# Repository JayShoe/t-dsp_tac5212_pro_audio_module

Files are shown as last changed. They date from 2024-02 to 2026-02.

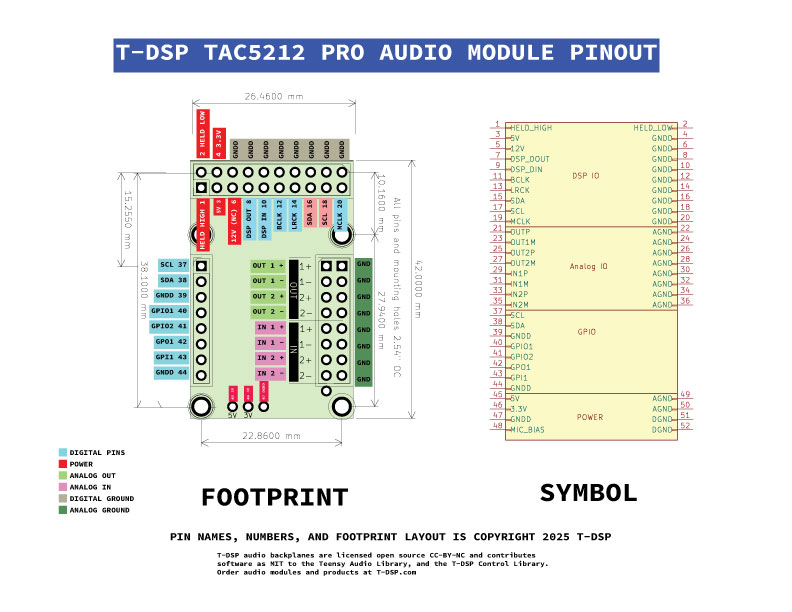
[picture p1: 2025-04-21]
documentation/T-DSP-TAC5212-PRO-AUDIO-MODULE-PINOUT.jpg

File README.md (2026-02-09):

# T-DSP TAC5212 Pro Audio Module

**Part of the [T-DSP](https://t-dsp.com) open modular audio platform.**

A compact (50mm x 34.5mm) stereo audio codec module built around the **Texas Instruments TAC5212** high-performance audio codec.

T-DSP TAC5212 Pro Audio Module

T-DSP TAC5212 Pro Audio Module - 3D Top
T-DSP TAC5212 Pro Audio Module - 3D Bottom

## About T-DSP

T-DSP is an open modular audio platform designed for musicians, engineers, and developers who want powerful digital signal processing in a flexible, hackable format. Built around the [Teensy](https://www.pjrc.com/teensy/) microcontroller and the [Teensy Audio Library](https://www.pjrc.com/teensy/td_libs_Audio.html), T-DSP combines studio-quality audio with a growing library of open-source modules for mixing, synthesis, effects, and more.

Whether you're building a custom digital mixer, crafting a unique instrument, or prototyping audio products, T-DSP gives you the tools to bring your ideas to life.

Join the community, contribute to the library, or grab a module and start patching. Learn more at [t-dsp.com](https://t-dsp.com).

## Overview

This codec module provides stereo ADC and DAC conversion and is one of the core building blocks of the T-DSP platform. It is designed as a **chip-on-board module** -- a complete, self-contained audio codec that solders directly onto a user-designed backplane PCB, just like any other component. A KiCad footprint is provided so you can drop the module into your own backplane design, add whatever jacks and connectors your application needs, and build a custom audio device without dealing with codec layout or analog design.

## Audio Capabilities

### Inputs (2 differential pairs)
- Line-level (consumer -10dBV or professional +4dBu)
- Instrument-level (guitar/bass) with external preamp/buffer (preamp and buffer modules are on the T-DSP project roadmap)
- Microphone (dynamic, with up to 12dB analog channel gain and additional digital gain)
- Programmable input impedance (5k/10k/40k ohm), DC-coupled. Optional 100k ohm bias resistors on board.
- 2 VRMS full-scale differential input

### Outputs (2 differential pairs)
- Headphone drive (16-300 ohm, 62.5mW @ 16 ohm, ~31mW @ 32 ohm)
- Consumer line out (-10dBV)
- Professional balanced output (+4dBu)
- 10 ohm output impedance, 2 VRMS differential output

## Digital Interface

- **I2S/PCM** audio data (DIN, DOUT, BCLK, LRCK, MCLK)
- **I2C** control bus for codec register configuration
- **GPIO** pins for additional control and sensing

The T-DSP platform is developed with [Teensy](https://www.pjrc.com/teensy/) and the [Teensy Audio Library](https://www.pjrc.com/teensy/td_libs_Audio.html), but the module uses standard I2S and I2C interfaces and can work with any compatible microcontroller or DSP platform.

## Modular Architecture

The module connects to your backplane via **2.54mm (0.1") header pins** (52 pins total), organized into functional groups. Headers can be male/female for a removable connection, or soldered permanently with straight pins:

- **DSP IO** (20 pins) -- digital audio (I2S), I2C control, MCLK, and power. Also available as a 20-pin ribbon header for off-board connection via standard ribbon cable.
- **Analog IO** (16 pins) -- stereo input and output pairs with analog ground references.
- **GPIO** (8 pins) -- additional I2C, general-purpose IO, and digital ground.
- **Power** (8 pins) -- 5V, 3.3V, MIC_BIAS, and ground lines.

T-DSP TAC5212 Pro Audio Module Pinout

### Backplane Integration

A KiCad footprint for the module is included in `/lib_fp/`, allowing you to import it directly into your own backplane PCB design. You handle the jacks, connectors, and mechanical layout on your backplane -- the module takes care of codec, filtering, and power regulation.

T-DSP TAC5212 Pro Audio Module Footprint

**Example backplanes built with the T-DSP module:**

Backplane example - prototype

Backplane example - 3D front
Backplane example - 3D back

### Multi-Module Chaining

Because the digital outputs are buffered on each module, multiple modules can run together on the same digital bus. You can daisy-chain modules in two ways:

- **On the backplane** -- route the digital bus as board traces between multiple module footprints.
- **Via ribbon cable** -- use a ribbon cable with multiple taps to connect up to 4 modules per chain.

System designers only need to focus on analog signal routing. The buffered digital bus works reliably over longer distances and across many modules.

## On-Board Circuitry

- LDO regulator for clean 3.3V analog power
- Buffered digital outputs for reliable backplane distribution
- TVS protection on audio outputs
- Ferrite bead RF filtering on audio inputs
- Solder jumpers for I2C address configuration
- Power indicator LED

The T-DSP platform has gone through several design iterations. The bench prototype below is from an earlier version of the project -- a different module architecture that helped shape the current design.

Earlier T-DSP prototype on the bench

## Project Files

| Directory | Contents |
|---|---|
| `/3d_models/` | 3D models for PCB components and enclosure |
| `/documentation/` | TAC5212 datasheets, [schematic PDF](documentation/t-dsp-tac5212-schematic.pdf), [footprint drawing](documentation/t-dsp-tac5212-footprint.pdf), and [3D model (STL)](documentation/t-dsp_tac5212_pro_audio_module.stl). View online: [schematic](https://kicanvas.org/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) and [PCB layout](https://kicanvas.org/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) via KiCanvas |
| `/lib_fp/` | Custom KiCad footprint libraries |
| `/lib_sch/` | Custom KiCad schematic symbol libraries |
| `/scripts/` | LCSC enrichment and BOM verification scripts |

## Building Manufacturing Files

Manufacturing files (gerbers, drill, BOMs, CPL, interactive BOM) are generated automatically by [KiBot](https://github.com/INTI-CMNB/KiBot) via GitHub Actions on every push to `main`. Download the ZIP from the **Actions** tab or from **Releases**.

The ZIP includes:
- Gerbers and drill files for any PCB fabricator
- JLCPCB BOM (`*_bom_JLCPCB.csv`) with LCSC part numbers
- Generic BOM (`*_bom_generic.csv`) with manufacturer part numbers
- Pick and place / CPL file
- Schematic PDF and PCB layout PDF
- Interactive BOM (also deployed live: [view iBOM](https://t-dsp.github.io/t-dsp_tac5212_pro_audio_module/ibom.html))

To build locally, install [Docker](https://www.docker.com/) and run:

```powershell
docker run --rm -v "${PWD}:/workspace" -w /workspace ghcr.io/inti-cmnb/kicad9_auto:latest kibot -c .kibot.yaml -b t-dsp_tac5212_pro_audio_module.kicad_pcb -e t-dsp_tac5212_pro_audio_module.kicad_sch -d manufacturing
```

Output files appear in `manufacturing/t-dsp_tac5212_pro_audio_module/`.

## Related Projects

Browse all T-DSP modules and backplanes on the [T-DSP GitHub organization](https://github.com/orgs/t-dsp/repositories).

## Status

This revision has not yet been built. The previous board was functional but had a few signal routing errors and needed a redesign of the analog output stage for low-impedance headphone drive. Those issues have been addressed in the current design.

If you build one, we'd love to hear how it goes -- please open an issue or reach out with your findings.

## Contact

For consulting, custom backplane design, or commercial licensing inquiries, reach out via [LinkedIn](https://linkedin.com/in/jayshoe).

## License

This project is licensed under the [Creative Commons Attribution-NonCommercial-ShareAlike 4.0 International (CC BY-NC-SA 4.0)](https://creativecommons.org/licenses/by-nc-sa/4.0/).

You are free to share and adapt this work for non-commercial purposes, as long as you give appropriate credit and distribute any derivatives under the same license.

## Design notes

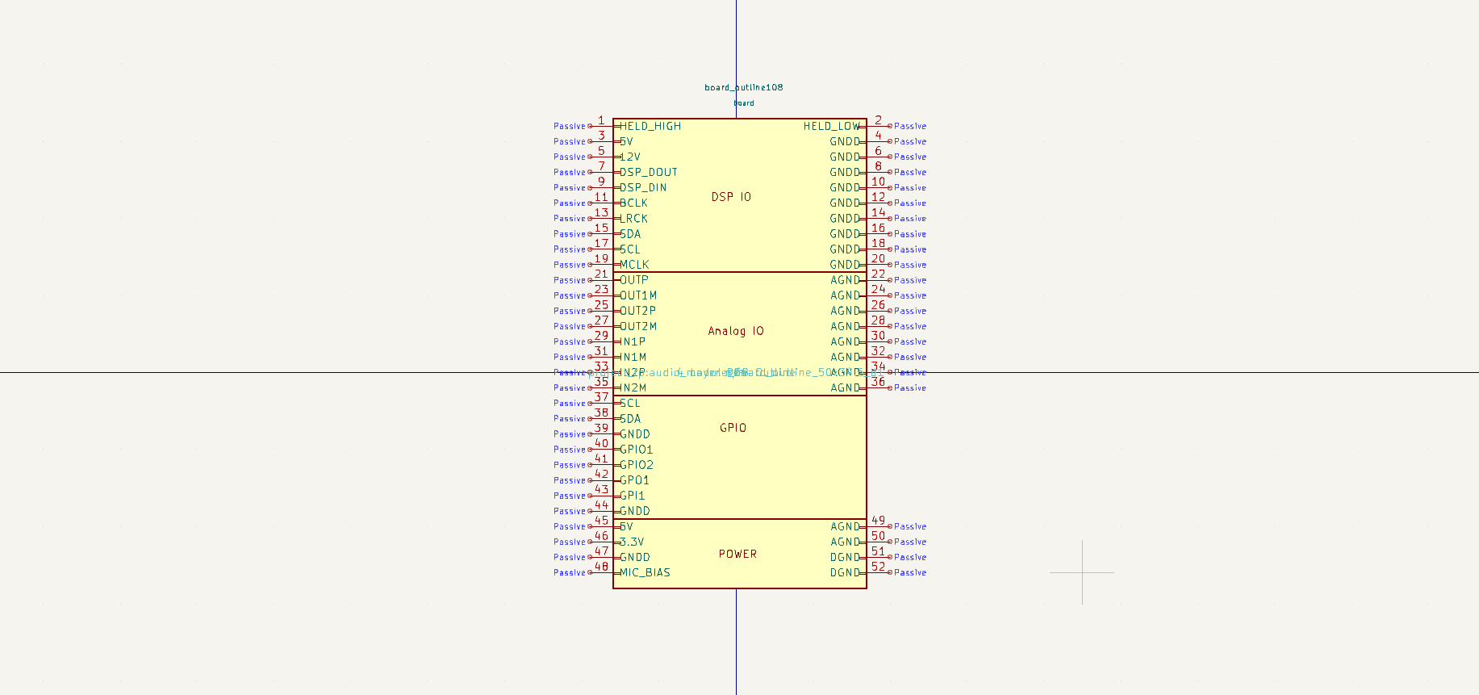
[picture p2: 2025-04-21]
documentation/T-DSP-TAC5212-PRO-AUDIO-MODULE-SYMBOL.png

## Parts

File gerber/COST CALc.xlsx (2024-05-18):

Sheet: TAC5212
Items | 1 quantity price | 100 price | 500 price | 1000 price | 2000 | 3000
components | 15.53 | 5.09 | 3.48 | 3.19 | 2.98 | 2.84
tacXXXX | 9.239 | 8.096 | 5.676 | 4.574 | 4.574 | 4.574
board | 2 | 0.33 | 0.08 | 0.08 | 0.08 | 0.08
assembly | 10 | 10 | 10 | 10 | 10 | 10
Total | 36.769 | 23.516 | 19.236 | 17.844 | 17.634 | 17.494
Price | 147.076 | 94.064 | 76.944 | 71.376 | 70.536 | 69.976
200 | 0.05 | 10

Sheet: TAC5112
Items | 1 quantity price | 100 price | 500 price | 1000 price | 2000 | 3000
components | 15.53 | 5.09 | 3.48 | 3.19 | 2.98 | 2.84
tacXXXX | 4.448 | 3.898 | 2.733 | 2.202 | 2.202 | 2.202
board | 2 | 0.33 | 0.08 | 0.08 | 0.08 | 0.08
assembly | 10 | 10 | 10 | 10 | 10 | 10
Total | 31.978 | 19.318 | 16.293 | 15.472 | 15.262 | 15.122
Price | 127.912 | 77.272 | 65.172 | 61.888 | 61.048 | 60.488

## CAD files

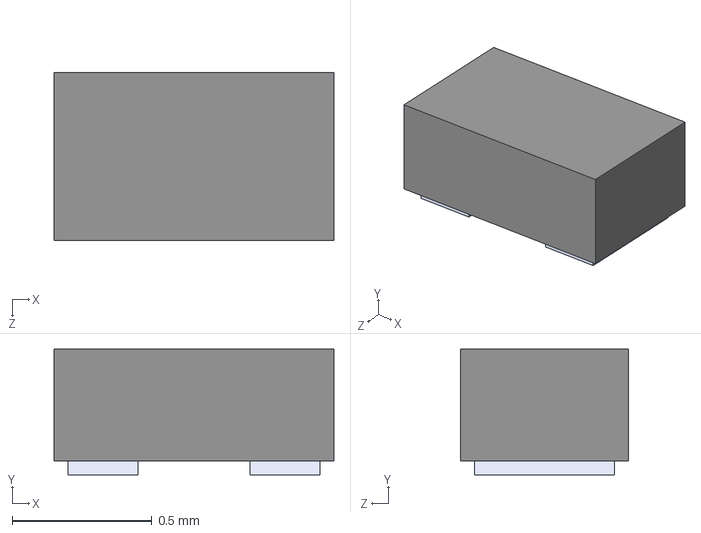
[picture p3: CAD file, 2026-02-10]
3d_models/TPD1E10B06DPYR.STEP
1.00 x 0.45 x 0.6 mm

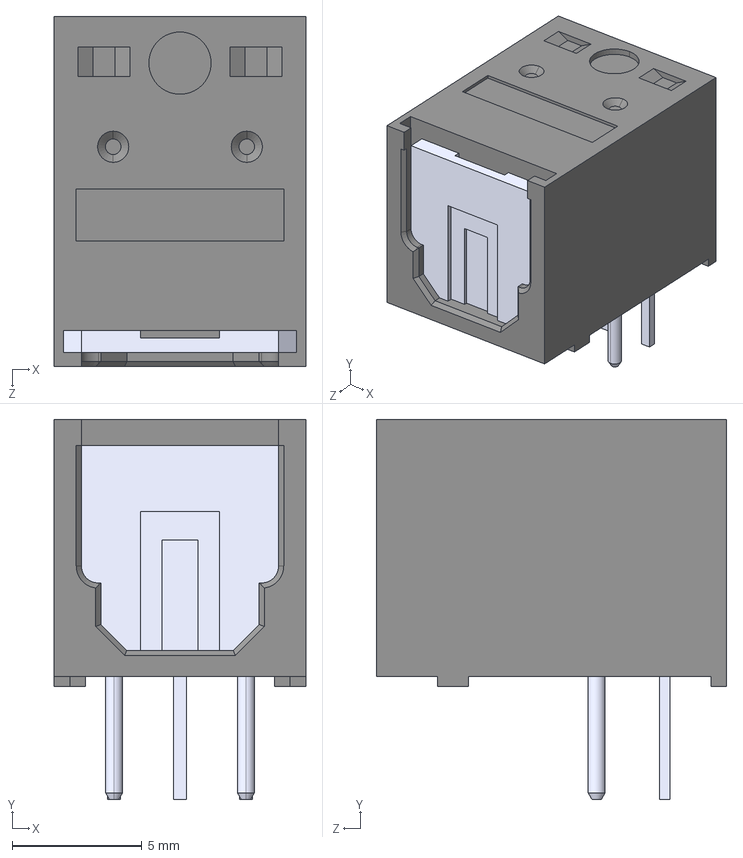
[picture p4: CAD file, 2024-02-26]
lib_sch/PLT133_T10W/PLT133_T10W.step
9.70 x 14.7 x 13.5 mm

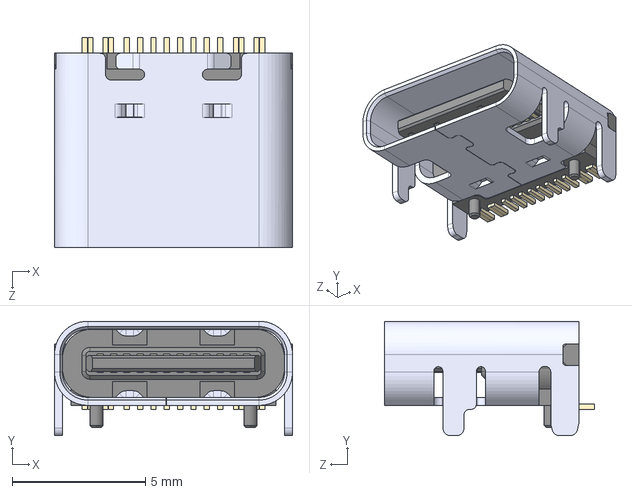
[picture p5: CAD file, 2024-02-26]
lib_sch/TYPE-C-31-M-12/TYPE-C-31-M-12.step
8.94 x 4.30 x 7.90 mm

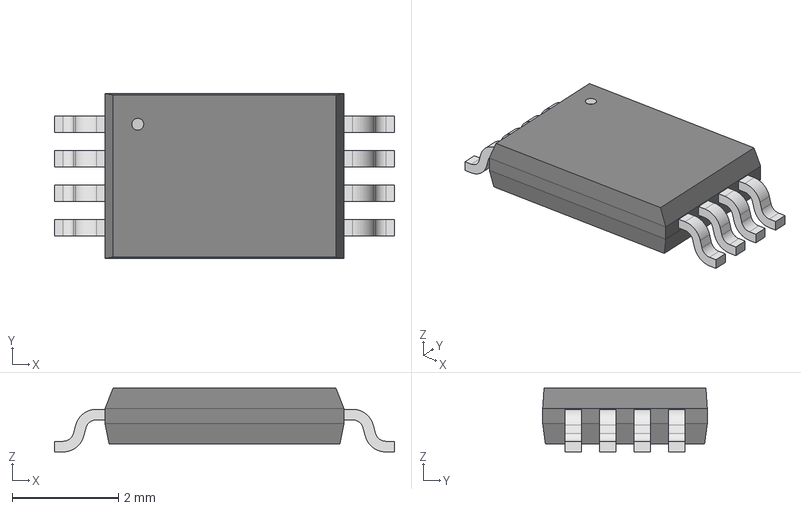
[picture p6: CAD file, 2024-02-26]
lib_sch/ul_23LC1024IST/2020-04-10_17-26-26/STEP/TSSOP8_MC.step
6.40 x 3.10 x 1.20 mm

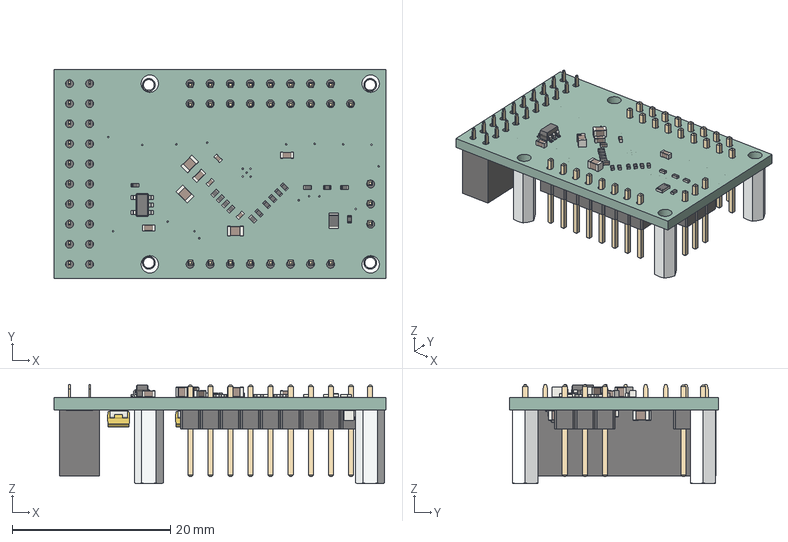
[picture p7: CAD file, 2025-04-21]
tlv320aic3105_audio_board50.step
42.0 x 26.5 x 12.5 mm
R_0402_1005Metric x 16
PinHeader_1x08_P254mm_Vertical x 2
PinHeader_1x09_P254mm_Vertical
PinSocket_2x10_P2.54mm_Vertical
PinHeader_1x03_P254mm_Vertical
C_0805_2012Metric x 9
C_0402_1005Metric x 3
SOT_23_5 x 2
C_0603_1608Metric x 13
R_0805_2012Metric
R_0603_1608Metric x 4
CP_EIA_3528_21_Kemet_B x 4
_autosave-tac5212_audio_board_single_ended_PCB

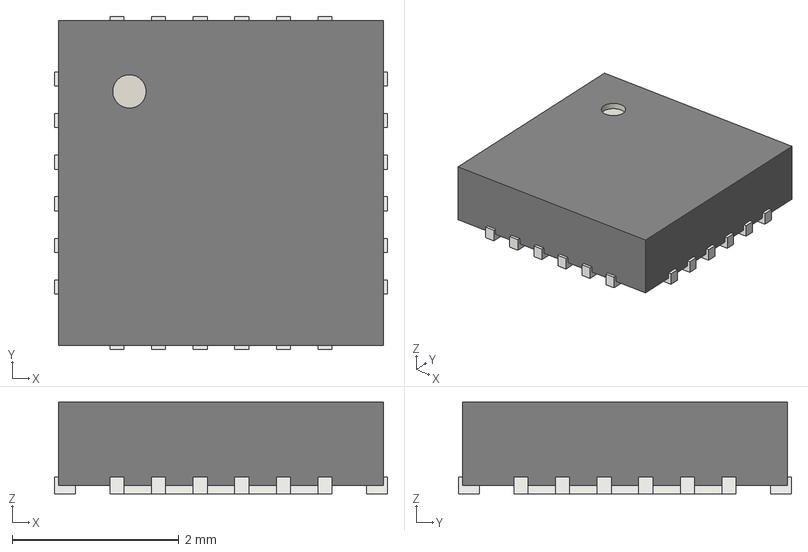
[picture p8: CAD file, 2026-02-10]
3d_models/VQFN-24-1EP_4x4mm_P0.5mm_EP2.45x2.45mm.step
4.00 x 4.00 x 1.10 mm

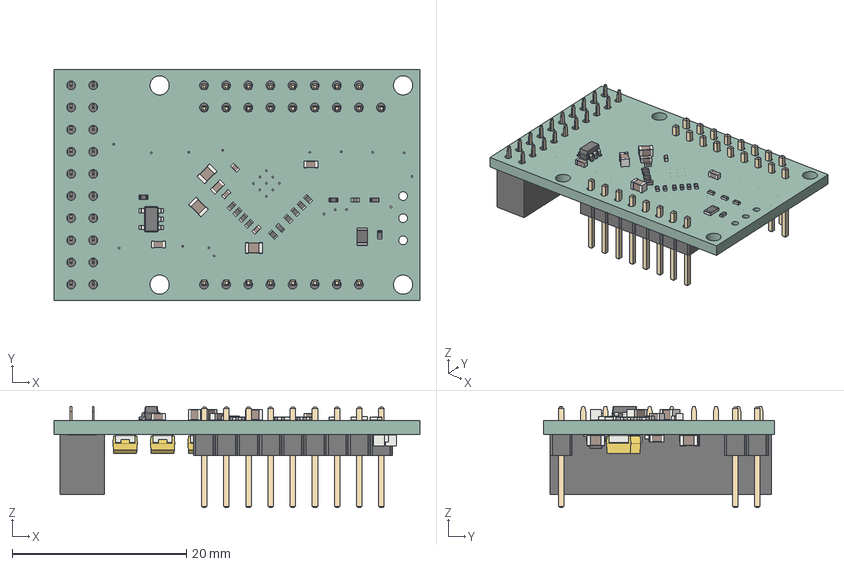
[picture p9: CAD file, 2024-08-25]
tac5212_audio_board_single_ended.step
42.0 x 26.5 x 11.6 mm
R_0402_1005Metric x 15
PinHeader_1x08_P254mm_Vertical x 2
PinHeader_1x09_P254mm_Vertical
PinSocket_2x10_P254mm_Vertical
C_0805_2012Metric x 9
C_0402_1005Metric x 3
SOT_23_5 x 2
C_0603_1608Metric x 12
R_0805_2012Metric
R_0603_1608Metric x 4
CP_EIA_3528_21_Kemet_B x 4
_autosave-tac5212_audio_board_single_ended_PCB

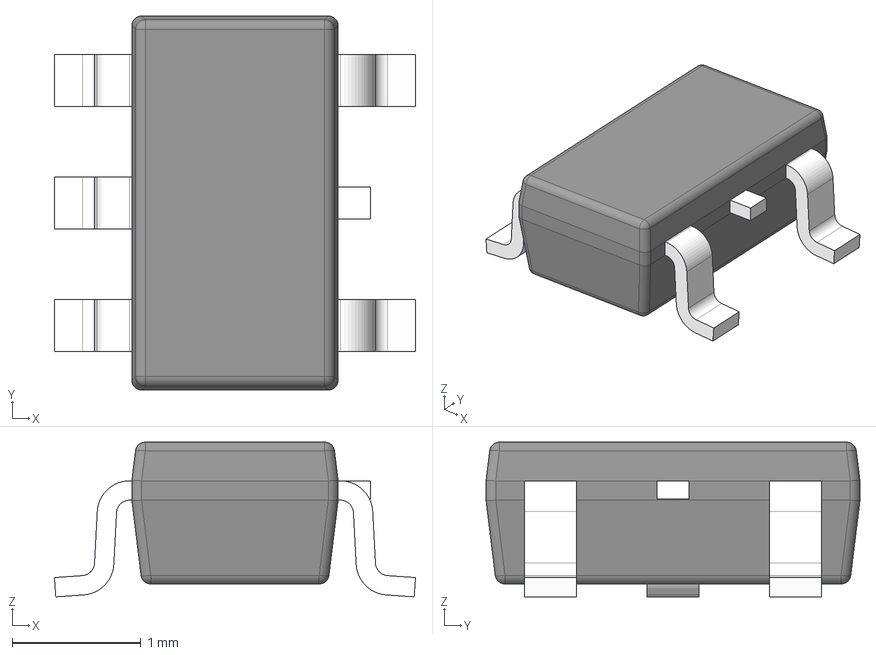
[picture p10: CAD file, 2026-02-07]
3d_models/SN74LVC1G66DBVR.stp
2.80 x 2.90 x 1.20 mm
BODY-SOT
LEAD-SOT x 5
LEAD-DUMMY

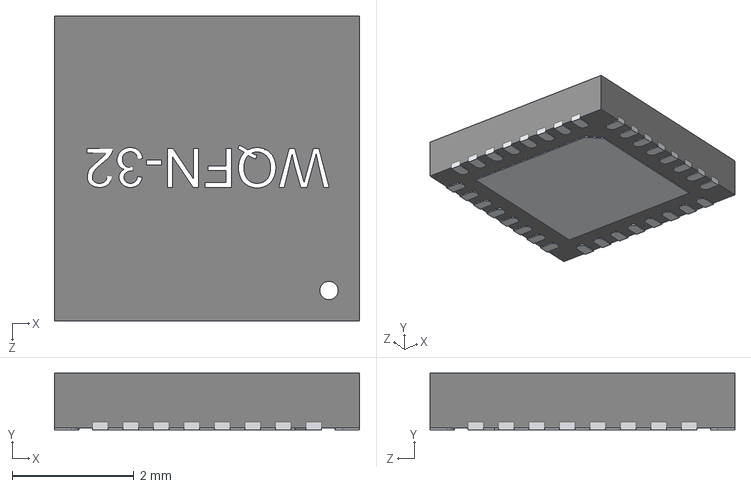
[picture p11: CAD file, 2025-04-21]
3d_models/WQFN-32.step
5.00 x 0.93 x 5.00 mm

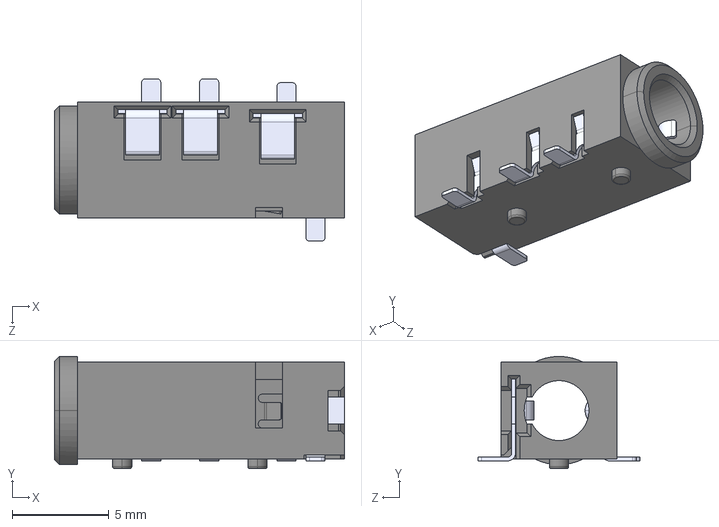
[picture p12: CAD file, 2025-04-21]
3d_models/SJ2-3574A-SMT-TR.step
15.0 x 5.80 x 8.40 mm

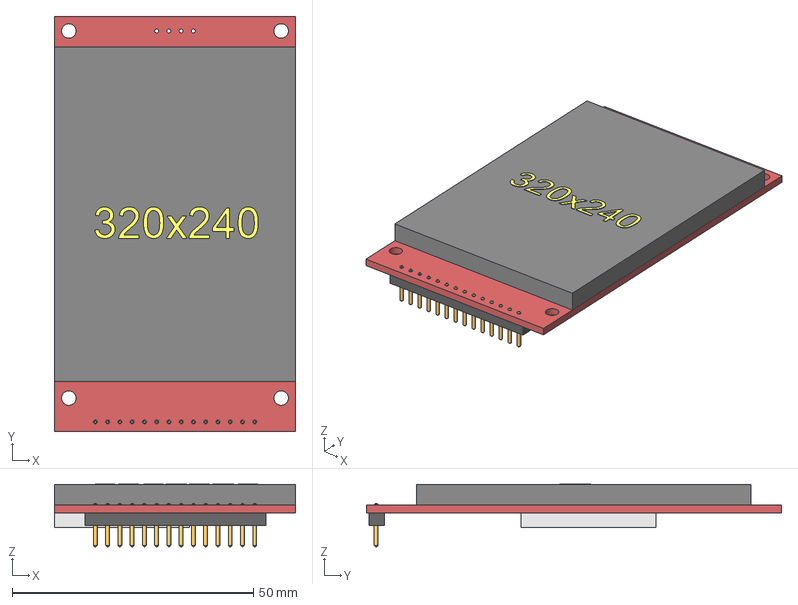
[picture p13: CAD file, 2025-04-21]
3d_models/TFT_320x240_touch_r0.step
50.0 x 86.0 x 13.1 mm
Body-header
Body-pins
Body-display
Body-sdcard
Body-board

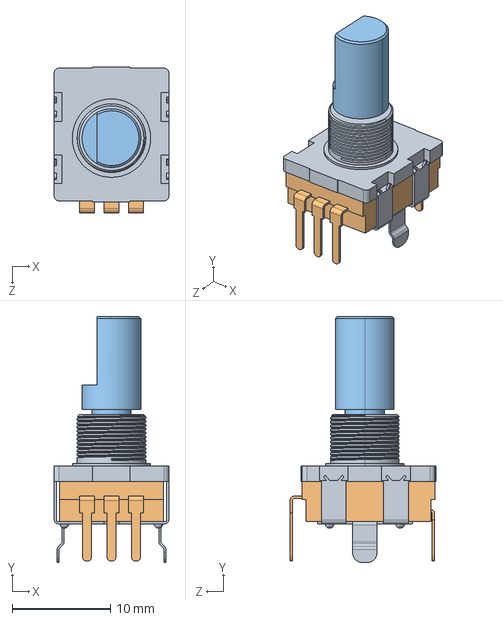
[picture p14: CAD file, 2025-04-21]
3d_models/EN11-HSM1AF15.STEP
11.7 x 25.1 x 14.9 mm

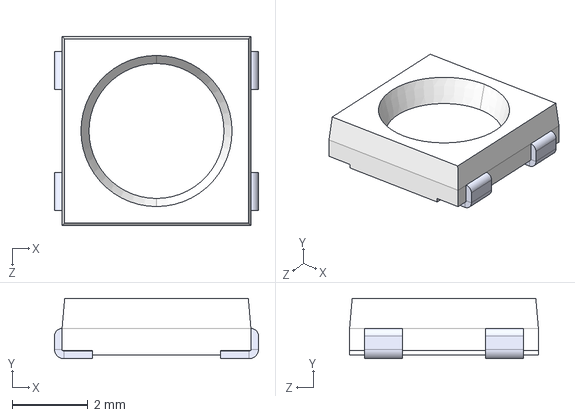
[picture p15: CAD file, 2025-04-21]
3d_models/SK6812.step
5.40 x 1.60 x 5.00 mm

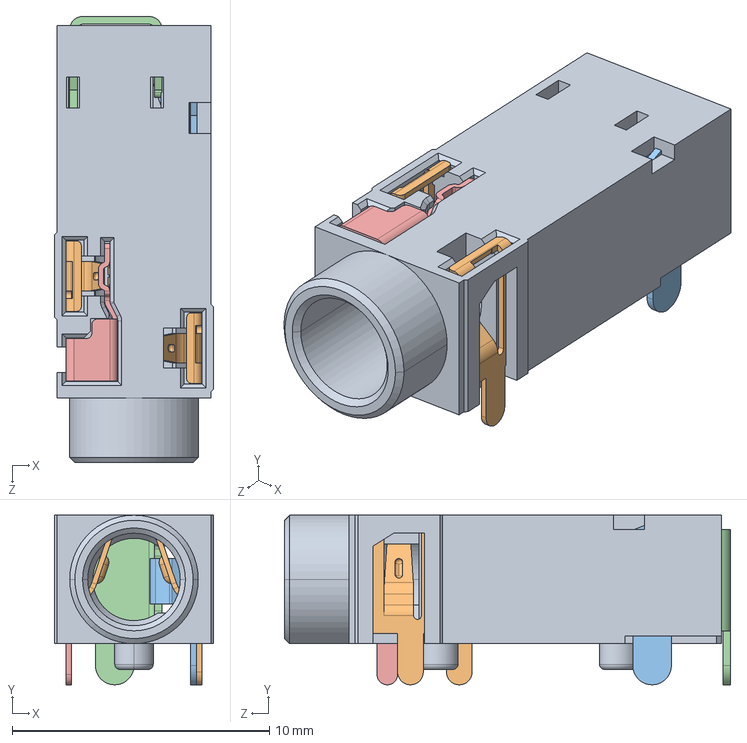
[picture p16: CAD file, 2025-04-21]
3d_models/Same_Sky_SJ3-35083D-TR.step
6.20 x 6.60 x 17.3 mm

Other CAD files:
lib_sch/ul_23LC1024IST/2020-04-10_17-26-26/STEP/TSSOP8_MC-M.step
lib_sch/ul_23LC1024IST/2020-04-10_17-26-26/STEP/TSSOP8_MC-L.step
3d_models/LED_SK6812MINI-E.step
3d_models/1808--3DModel-STEP-630548.STEP
3d_models/2120--3DModel-STEP-630548.STEP
3d_models/3-D NC3MAH.stp
3d_models/3-D NCJ6FAH.stp
3d_models/3-D NCJ6FI-H-0.stp
3d_models/3-d-nmj6hcd3.stp
3d_models/3.5MM_STEREO_35RAPC4BHN2.STEP
3d_models/35RAPC3BH3.STEP
3d_models/35RAPC7JS.STEP
3d_models/35RAPC7JS_SIMPLIFIED.step
3d_models/3_2SPI-TFT-Modul_ILI9341.STEP
3d_models/4691.step
3d_models/74LS00.step
3d_models/Bracket 4-40 621.STEP
3d_models/COMBO-NCJ6FA-H.step
3d_models/COMBO_XLR_NCJ6FI-H-0.stp
3d_models/DC_BARREL_PJ-202AH.step
3d_models/DIN-5.STEP
3d_models/FCR6842032R ORJ3.stp
3d_models/FCR6842032T OTJ3.stp
3d_models/J1B1211CCD.STEP
3d_models/JST - XH - Thru (V) - 2Pin - 2.54mm.stp
3d_models/MicroFit3-43045-0428.stp
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

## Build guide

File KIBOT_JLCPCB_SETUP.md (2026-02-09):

# KiBot JLCPCB Setup Notes

Reference for generating JLCPCB-ready manufacturing files from KiCad using KiBot + Docker.

## Prerequisites

- **Docker**: Required (kicad-cli and KiBot are NOT installed locally)
- **Docker image**: `ghcr.io/inti-cmnb/kicad9_auto:latest` (bundles KiBot + KiCad 9)
- Pull it first: `docker pull ghcr.io/inti-cmnb/kicad9_auto:latest`

## Project Files

```
t-dsp_tac5212_pro_audio_module.kicad_pro
t-dsp_tac5212_pro_audio_module.kicad_pcb   (4-layer: F.Cu, In1.Cu, In2.Cu, B.Cu)
t-dsp_tac5212_pro_audio_module.kicad_sch   (LCSC field with 237 occurrences)
```

## Run Command

PowerShell:
```powershell
docker run --rm -v "${PWD}:/workspace" -w /workspace ghcr.io/inti-cmnb/kicad9_auto:latest kibot -c .kibot.yaml -b t-dsp_tac5212_pro_audio_module.kicad_pcb -e t-dsp_tac5212_pro_audio_module.kicad_sch
```

cmd.exe:
```cmd
docker run --rm -v "%cd%:/workspace" -w /workspace ghcr.io/inti-cmnb/kicad9_auto:latest kibot -c .kibot.yaml -b t-dsp_tac5212_pro_audio_module.kicad_pcb -e t-dsp_tac5212_pro_audio_module.kicad_sch
```

Git Bash (must disable MSYS path conversion):
```bash
MSYS_NO_PATHCONV=1 docker run --rm -v "${PWD}:/workspace" -w /workspace ghcr.io/inti-cmnb/kicad9_auto:latest kibot -c .kibot.yaml -b t-dsp_tac5212_pro_audio_module.kicad_pcb -e t-dsp_tac5212_pro_audio_module.kicad_sch
```

## Output

All files go to `JLCPCB/` directory:
- Gerber files (.gtl, .gbl, .g1, .g2, .gto, .gbo, .gts, .gbs, .gtp, .gbp, .gm1)
- Drill files (-PTH.drl, -NPTH.drl, drill maps)
- BOM CSV: columns = Comment, Designator, Footprint, LCSC Part #
- CPL CSV: columns = Designator, Val, Package, Mid X, Mid Y, Rotation, Layer
- ZIP containing everything above

## Issues to Fix Before Running

### 1. Malformed Reference Designators (BLOCKING)

KiBot will ERROR and skip BOM/CPL generation if any reference designator starts with a digit.

Two components have this problem:
- **`5V108`** — Device:NetTie_2, value "jumper", footprint project_fp:jumper_slice_1mm, DNP, at (57.15, 226.06) in schematic
- **`3V108`** — Device:NetTie_2, value "jumper", footprint project_fp:jumper_slice_1mm, DNP, at (116.84, 355.6) in schematic

**Fix in KiCad**: Rename these to valid designators (e.g. NT110, NT111 or JP110, JP111). KiCad will automatically update the associated net names. Do this in KiCad's schematic editor (not by text editing) so it handles all the cross-references properly.

Note: NT108 and NT109 already exist in the schematic (different net ties with footprint NetTie-2_SMD_Pad0.2mm), so don't use those numbers.

Gerbers generate fine from the PCB file regardless — only BOM/CPL are blocked.

### 2. Non-Blocking Warnings (cosmetic, won't prevent output)

**Trailing spaces in TAC5212EVM fields (W037):**
- D116: `LTST-C170KRKT ` (trailing space)
- R115, R118, R119: `ERJ-2GE0R00X ` (trailing space)
- Fix: Edit these fields in KiCad symbol properties, remove trailing space

**Missing library components (W043):**
- `proejct_lib:Jumper_NO_Small-Device_1` and `_2`
- Note the typo: "proejct" not "project"
- The whole project uses `proejct_lib` throughout — this is a legacy typo baked into the project

**Malformed component values (W020/W127):**
- C113, C114, C120, C122: `0.0047µF (4.7nF)` — KiBot can't parse this format. Consider `4.7nF`
- C124: `10UF confirm polarity` — extra text. Consider `10uF`
- R120: `2.21k ohm` — redundant "ohm". Consider `2.21k`

**BOM field conflicts (W004):**
These happen when KiBot groups components with same Value but different metadata. Not output-breaking but may indicate real BOM issues:
- C109,C112,C116 (0402) grouped with C128,C129 (0603) — same value "0.1uF" but different packages
- C124-C127: package mismatch C0805 vs C0603
- R120,R121,R126: different LCSC codes (C138019 vs C60491) — R126 may be a different value (100K vs 2.21k)

## .kibot.yaml Configuration

Place this file at the repo root as `.kibot.yaml`:

```yaml
# KiBot configuration for JLCPCB manufacturing outputs
# Project: T-DSP TAC5212 Pro Audio Module
# Board: 4-layer (F.Cu, In1.Cu, In2.Cu, B.Cu)

kibot:
  version: 1

filters:
  - name: only_jlc_parts
    comment: 'Only parts with LCSC code'
    type: generic
    include_only:
      - column: 'LCSC'
        regex: '^C\d+'

variants:
  - name: rotated
    comment: 'JLCPCB rotation correction'
    type: kibom
    variant: rotated
    pre_transform: _rot_footprint_jlcpcb

outputs:
  - name: JLCPCB_gerbers
    comment: Gerbers compatible with JLCPCB
    type: gerber
    dir: JLCPCB
    options:
      exclude_edge_layer: true
      exclude_pads_from_silkscreen: true
      plot_sheet_reference: false
      plot_footprint_refs: true
      plot_footprint_values: false
      force_plot_invisible_refs_vals: false
      tent_vias: true
      use_protel_extensions: true
      create_gerber_job_file: false
      disable_aperture_macros: true
      gerber_precision: 4.6
      use_gerber_x2_attributes: false
      use_gerber_net_attributes: false
      line_width: 0.1
      subtract_mask_from_silk: true
      inner_extension_pattern: '.g%n'
    layers:
      - F.Cu
      - B.Cu
      - In1.Cu
      - In2.Cu
      - F.SilkS
      - B.SilkS
      - F.Mask
      - B.Mask
      - F.Paste
      - B.Paste
      - Edge.Cuts

  - name: JLCPCB_drill
    comment: Drill files compatible with JLCPCB
    type: excellon
    dir: JLCPCB
    options:
      pth_and_npth_single_file: false
      pth_id: '-PTH'
      npth_id: '-NPTH'
      metric_units: true
      map: gerber
      route_mode_for_oval_holes: false
      output: "%f%i.%x"

  - name: JLCPCB_position
    comment: Pick and place file, JLCPCB style
    type: position
    dir: JLCPCB
    options:
      variant: rotated
      output: '%f_cpl_jlc.%x'
      format: CSV
      units: millimeters
      separate_files_for_front_and_back: false
      only_smd: true
      columns:
        - id: Ref
          name: Designator
        - Val
        - Package
        - id: PosX
          name: "Mid X"
        - id: PosY
          name: "Mid Y"
        - id: Rot
          name: Rotation
        - id: Side
          name: Layer

  - name: JLCPCB_bom
    comment: BoM for JLCPCB
    type: bom
    dir: JLCPCB
    options:
      output: '%f_bom_jlc.%x'
      exclude_filter: 'only_jlc_parts'
      ref_separator: ','
      columns:
        - field: Value
          name: Comment
        - field: References
          name: Designator
        - Footprint
        - field: 'LCSC'
          name: 'LCSC Part #'
      csv:
        hide_pcb_info: true
        hide_stats_info: true
        quote_all: true

  - name: JLCPCB
    comment: ZIP file for JLCPCB
    type: compress
    dir: JLCPCB
    options:
      files:
        - from_output: JLCPCB_gerbers
          dest: /
        - from_output: JLCPCB_drill
          dest: /
        - from_output: JLCPCB_position
          dest: /
        - from_output: JLCPCB_bom
          dest: /
```

## Key Config Notes

- **LCSC field name**: This project uses `LCSC` (not `LCSC#` which is the KiBot sample default)
- **Rotation filter**: `_rot_footprint_jlcpcb` is a KiBot built-in that adjusts component rotations to match JLCPCB's coordinate system
- **BOM filter**: `exclude_filter: 'only_jlc_parts'` confusingly acts as an include filter — it includes only parts with valid LCSC codes
- **Existing panel outputs**: `panel/jlcpcb_1x1/gerbers/` has manually-generated JLCPCB files (bom.csv, pos.csv) for reference

## Checklist

1. [ ] Fix `5V108` and `3V108` reference designators in KiCad (rename to NT110/NT111 or similar)
2. [ ] Place `.kibot.yaml` at repo root (copy from this file)
3. [ ] Run Docker command above
4. [ ] Verify JLCPCB/ output: gerbers, drill, BOM CSV, CPL CSV, ZIP
5. [ ] Optionally fix cosmetic warnings (trailing spaces, malformed values)
6. [ ] Commit JLCPCB/ output files to repo

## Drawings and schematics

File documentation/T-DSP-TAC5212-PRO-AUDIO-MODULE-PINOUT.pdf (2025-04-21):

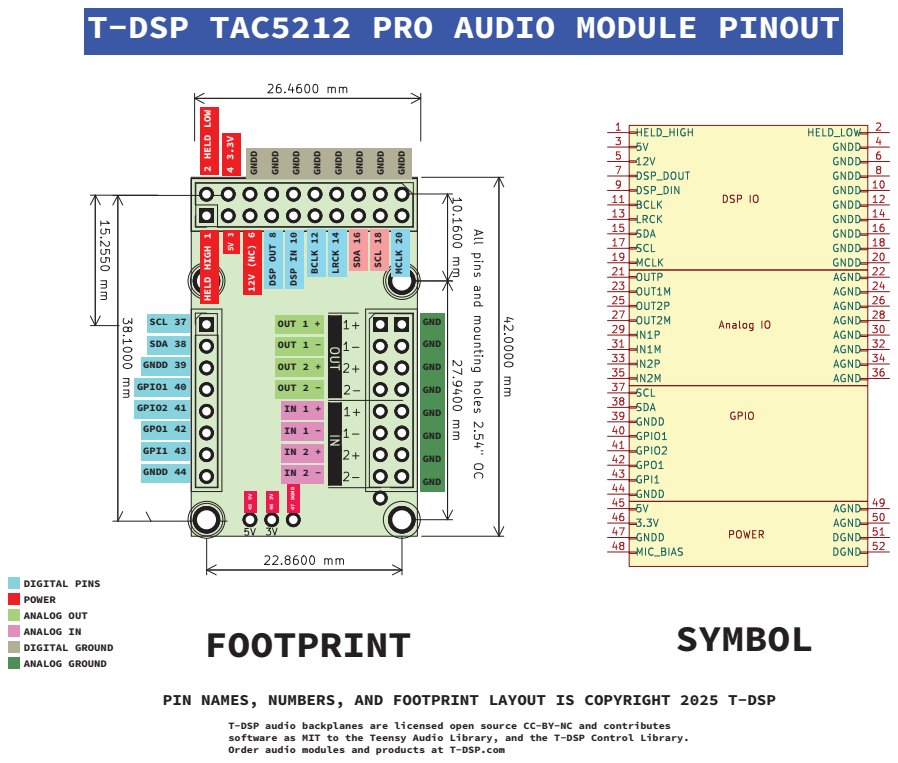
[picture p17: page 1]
T-DSP TAC5212 PRO AUDIO MODULE PINOUT 2 HELD LOW; 12V (NC) 6 DSP OUT 8 DSP IN 10 BCLK 12 LRCK 14 SDA 16 SCL 18 MCLK 20 HELD HIGH 1; GNDD GNDD GNDD GNDD GNDD GNDD GNDD GNDD; SCL 37 SDA 38 GNDD 39 GPIO1 40 GPIO2 41 GPO1 42 GPI1 43 GNDD 44; OUT 1 + OUT 1 - OUT 2 + OUT 2 - IN 1 + IN 1 - IN 2 + IN 2 -; GND; 47 DGND; DIGITAL PINS POWER ANALOG OUT ANALOG IN DIGITAL GROUND ANALOG GROUND; FOOTPRINT; SYMBOL

PIN NAMES, NUMBERS, AND FOOTPRINT LAYOUT IS COPYRIGHT 2025 T-DSP

T-DSP audio backplanes are licensed open source CC-BY-NC and contributes
software as MIT to the Teensy Audio Library, and the T-DSP Control Library.
Order audio modules and products at T-DSP.com

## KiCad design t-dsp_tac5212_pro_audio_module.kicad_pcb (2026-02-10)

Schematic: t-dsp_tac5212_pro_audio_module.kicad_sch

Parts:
ADD108: 0x50 | 0xA0; SolderJumper-2_Open_Pad0.5x1.0mm_ADDR; not fitted
ADD110: 0x52 | 0xA4; SolderJumper-2_Open_Pad0.5x1.0mm_ADDR; not fitted
ADD111: 0x53 | 0xA6; SolderJumper-2_Open_Pad0.5x1.0mm_ADDR; not fitted
ADD112: 0x51 | 0xA2; SolderJumper-2_Open_Pad0.5x1.0mm_ADDR; not fitted
C108, C111, C115: 10uF; C_0805_2012Metric_Pad1.18x1.45mm_HandSolder; LCSC C2182156
C109, C112, C116, C128, C129: 0.1uF; C_0402_1005Metric; LCSC C106994
C110, C117, C121, C123: 47uF; CP_EIA-3528-21_Kemet-B_Pad1.50x2.35mm_HandSolder; LCSC C284844; not fitted
C113, C114, C120, C122: 0.0047µF (4.7nF); C_0603_1608Metric_Pad1.08x0.95mm_HandSolder; LCSC C1870901
C118, C119: 1uF; C_0603_1608Metric_Pad1.08x0.95mm_HandSolder; LCSC C2172920
C124: 10UF confirm polarity; C_0603_1608Metric_Pad1.08x0.95mm_HandSolder; LCSC C2167896
C125, C126, C127: 10UF; C_0603_1608Metric_Pad1.08x0.95mm_HandSolder; LCSC C2167896
C130: 47uF; C_0805_2012Metric_Pad1.15x1.40mm_HandSolder; LCSC C16780
C131: 10uF; C_0805_2012Metric_Pad1.15x1.40mm_HandSolder; LCSC C2182156
D108, D109, D110, D111, D112: TPD1E10B06; D_0402_1005Metric_Pad0.77x0.64mm_HandSolder; LCSC C48260
D113, D114, D115: TPD1E1B04 - 0402 size; D_0402_1005Metric_Pad0.77x0.64mm_HandSolder; LCSC C48260
D116: RED LED; D_0805_2012Metric_custom; LCSC C94868
DOUT108: Jump DOUT1; jumper_slice_disconnected_alt-text; not fitted
E108, E109: jumper; jumper_slice; not fitted
FB108, FB109, FB110, FB111: BLM21A601S - BLM21AG601SH1; L_0805_2012Metric_Pad1.18x1.45mm_HandSolder; LCSC C437406
G108, G109, G110, G111, G112: VIA; SMD_ROUTING_PAD; not fitted
G113, G114, G115, G116, G120, G121, G122, G124: VIA; via; not fitted
G117, G118, G119: jumper; jumper_slice; not fitted
G123: SMD ROUTING PAD; SMD_ROUTING_PAD; not fitted
GND108: BRIDGE; jumper_slice; not fitted
INM1, INM2: VIA; via; not fitted
INP1, INP2: VIA; via; not fitted
J3V108, J5V108: jumper; jumper_slice_1mm; not fitted
MCLK108: jumper; SolderJumper-2_P1.3mm_Open_Pad1.0x1.5mm_Master_Clock; not fitted
NT108, NT109: NetTie_2; NetTie-2_SMD_Pad0.2mm
OUTM1, OUTM2: VIA; via; not fitted
OUTP1, OUTP2: VIA; via; not fitted
PU_EN108: JUMPER; SolderJumper-2_Open_Pad0.5x1.0mm_PU; not fitted
R108, R111, R132, R135: 10 ohm; R_0603_1608Metric_Pad1.05x0.95mm_HandSolder; LCSC C22859
R109, R127, R131, R134: DNP; R_0603_1608Metric_Pad1.05x0.95mm_HandSolder; LCSC DNP; not fitted
R115, R118, R119: 0 Ohm; R_0402_1005Metric_Pad0.72x0.64mm_HandSolder; LCSC C242160
R116, R129, R133, R136: 0 ohm; R_0603_1608Metric_Pad1.05x0.95mm_HandSolder; LCSC C21189
R117, R125: 27 ohm; R_0402_1005Metric_Pad0.72x0.64mm_HandSolder; LCSC C25105
R120, R121, R126: 2.21k ohm; R_0402_1005Metric; LCSC C138019
R122: 22.0k; R_0402_1005Metric; LCSC C82868
R123, R124: 4.7k; R_0402_1005Metric; LCSC C278641
R128: 2.21k ohm; R_0805_2012Metric_Pad1.20x1.40mm_HandSolder; Manufacturer_Part_Number CMP0805AFX-1000ELF; LCSC C138019; not fitted
R130, R137, R138, R139: 100K; R_0603_1608Metric_Pad1.05x0.95mm_HandSolder; LCSC C25803
SCL108: jumper; jumper_slice; not fitted
SCL109: jumper; jumper_slice_1mm; not fitted
SDA108: jumper; jumper_slice; not fitted
T108, T109, T110, T111: Tab
T*C108, T*C110: 10uF; C_0805_2012Metric_Pad1.18x1.45mm_HandSolder; LCSC C2182156
T*C109: 1uF; C_0603_1608Metric_Pad1.08x0.95mm_HandSolder; LCSC C2172920
TAC108-Q1: TAC5212-Q1; Texas_RHB0032E_VQFN-32-1EP_5x5mm_P0.5mm_EP3.45x3.45mm_Therm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; not fitted
TAC5212: TAC5212; VQFN-24-1EP_4x4mm_P0.5mm_EP2.45x2.45mm_ThermalVias; LCSC C44853694
U108: Single Buffer with Tri-state Passthru - SN74LVC1G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; SOT-353_SC-70-5; LCSC C113518
U109: 3.3v LDO - TLV74133PDBVR; SOT-23-5; LCSC C471862
board_outline108: board; audio_module_board_outline_50x34.5_e1; not fitted

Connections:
3.3V_A: J3V108.2, T*C110.1, U109.5 (OUT)
3.3V_LDO: J3V108.1, NT109.1, R122.2, R123.2, R126.1, board_outline108.46 (3.3V)
3.3V_THIN: C108.1, C109.1, NT109.2, TAC108-Q1.31 (AVDD), TAC5212.23 (AVDD)
3.3v_IDE: C111.1, C112.1, C128.1, C131.1, PU_EN108.2, SCL109.2, TAC108-Q1.7 (IOVDD), TAC5212.6 (IOVDD), U108.4 (OE^), U108.5 (VCC), board_outline108.4 (GNDD)
5V: C130.1, J5V108.1, NT108.1, board_outline108.45 (5V)
5V_THIN: NT108.2, T*C108.1, T*C109.1, U109.1 (IN)
5212_BCLK1: R119.1, board_outline108.11 (BCLK)
5212_DIN1: R118.1, board_outline108.7 (DSP_DOUT)
5212_DOUT1: DOUT108.1, R117.1, U108.1 (A)
5212_DOUT1+: DOUT108.2, R125.1, board_outline108.9 (DSP_DIN)
5212_LRCK1: R115.1, board_outline108.13 (LRCK)
5212_MCLK1: MCLK108.1, board_outline108.19 (MCLK)
5212_SCL: R121.1, SCL108.2, TAC108-Q1.9 (SCL), TAC5212.7 (SCL), board_outline108.37 (SCL)
5212_SDA: R120.1, SDA108.2, TAC108-Q1.10 (SDA), TAC5212.8 (SDA), board_outline108.38 (SDA)
DSP_SCL: SCL108.1, board_outline108.17 (SCL)
DSP_SDA: SDA108.1, board_outline108.15 (SDA)
EN_HELD_HIGH: C129.1, R128.1, U109.3 (EN), board_outline108.1 (HELD_HIGH)
Earth: C108.2, C109.2, C113.2, C114.2, C118.2, C119.1, C120.2, C122.2, D108.2 (K), D109.2 (K), D110.2 (K), D111.2 (K), D112.2 (K), D113.2 (K), D114.2 (K), D115.2 (K), E108.1, E109.2, G108.1, G109.1, G110.1, G111.1, G112.1, G113.1, G114.1, G115.1, G116.1, G119.2, G120.1, G121.1, G122.1, G123.1, GND108.2, R130.2, R137.2, R138.2, R139.2, board_outline108.22 (AGND), board_outline108.24 (AGND), board_outline108.26 (AGND), board_outline108.28 (AGND), board_outline108.30 (AGND), board_outline108.32 (AGND), board_outline108.34 (AGND), board_outline108.36 (AGND)
GNDD: ADD108.1, C111.2, C112.2, C115.2, C116.2, C128.2, C129.2, C130.2, C131.2, D116.1 (K), G117.2, G118.2, GND108.1, R124.2, TAC108-Q1.1 (VSS), TAC108-Q1.8 (IOVSS), TAC108-Q1.15 (BSTVSS), TAC108-Q1.26 (AVSS), TAC108-Q1.33 (VSS), TAC5212.25 (VSS), TAC5212.A1 (VSS), TAC5212.A2 (VSS), TAC5212.A3 (VSS), TAC5212.A4 (VSS), U108.3 (GND), board_outline108.6 (GNDD), board_outline108.8 (GNDD), board_outline108.10 (GNDD), board_outline108.12 (GNDD), board_outline108.14 (GNDD), board_outline108.16 (GNDD), board_outline108.18 (GNDD), board_outline108.20 (GNDD), board_outline108.39 (GNDD), board_outline108.44 (GNDD), board_outline108.47 (GNDD)
GPI1: MCLK108.2, TAC108-Q1.25 (GPI1A), TAC5212.12 (GPI1), board_outline108.43 (GPI1)
GPIO1: TAC108-Q1.11 (GPIO1), TAC5212.9 (GPIO1), board_outline108.40 (GPIO1)
GPIO2: TAC108-Q1.24 (GPI2A), TAC5212.10 (GPIO2), board_outline108.41 (GPIO2)
GPO1: TAC108-Q1.23 (GPO1A), TAC5212.11 (GPO1), board_outline108.42 (GPO1)
IN1M: C126.2, INM1.1, TAC108-Q1.19 (IN1M), TAC5212.16 (IN1M)
IN1M+: D114.1 (K), FB110.1, board_outline108.31 (IN1M)
IN1P: C127.2, INP1.1, TAC108-Q1.18 (IN1P), TAC5212.15 (IN1P)
IN1P+: D115.1 (K), FB111.1, board_outline108.29 (IN1P)
IN2M: C124.2, INM2.1, TAC108-Q1.21 (IN2M), TAC5212.18 (IN2M)
IN2M+: D112.1 (K), FB108.1, board_outline108.35 (IN2M)
IN2P: C125.2, INP2.1, TAC108-Q1.20 (IN2P), TAC5212.17 (IN2P)
IN2P+: D113.1 (K), FB109.1, board_outline108.33 (IN2P)
MICBIAS: C118.1, TAC108-Q1.17 (MICBIAS), TAC5212.14 (MICBIAS), board_outline108.48 (MIC_BIAS)
unnamed: ADD110.1, R122.1
unnamed: ADD111.1, R123.1
unnamed: ADD112.1, R124.1
unnamed: C110.1, C113.1, R108.1, R127.1, R129.2
unnamed: C114.1, C117.1, R109.1, R111.1, R116.2
unnamed: C120.1, C121.1, R131.1, R132.1, R133.2
unnamed: C122.1, C123.1, R134.1, R135.1, R136.2
unnamed: C124.1, FB108.2, R130.1
unnamed: C125.1, FB109.2, R137.1
unnamed: C126.1, FB110.2, R138.1
unnamed: C127.1, FB111.2, R139.1
unnamed: D116.2 (A), R126.2
unnamed: E108.2, board_outline108.49 (AGND)
unnamed: E109.1, board_outline108.50 (AGND)
unnamed: G117.1, board_outline108.51 (DGND)
unnamed: G118.1, board_outline108.52 (DGND)
unnamed: J5V108.2, board_outline108.3 (5V)
unnamed: PU_EN108.1, R120.2, R121.2
unnamed: R128.2, SCL109.1
unnamed: ADD108.2, ADD110.2, ADD111.2, ADD112.2, TAC108-Q1.22 (ADDRA), TAC5212.13 (ADDR)
unnamed: R119.2, TAC108-Q1.3 (BCLK), TAC5212.2 (BCLK)
unnamed: R118.2, TAC108-Q1.6 (DIN), TAC5212.5 (DIN)
unnamed: R117.2, TAC108-Q1.5 (DOUT), TAC5212.4 (DOUT)
unnamed: C115.1, C116.1, TAC108-Q1.2 (DREG), TAC5212.1 (DREG)
unnamed: R115.2, TAC108-Q1.4 (FSYNC), TAC5212.3 (FSYNC)
unnamed: C119.2, TAC108-Q1.32 (VREF), TAC5212.24 (VREF)
unnamed: R125.2, U108.2 (B)
unnamed: G119.1, T*C108.2, T*C109.2, T*C110.2, U109.2 (GND)
OUT1M: OUTM1.1, R109.2, R111.2, TAC108-Q1.27 (OUT1M), TAC5212.19 (OUT1M)
OUT1M+: C117.2, D109.1 (K), R116.1, board_outline108.23 (OUT1M)
OUT1P: OUTP1.1, R108.2, R127.2, TAC108-Q1.28 (OUT1P), TAC5212.20 (OUT1P)
OUT1P+: C110.2, D108.1 (K), R129.1, board_outline108.21 (OUTP)
OUT2M: OUTM2.1, R134.2, R135.2, TAC108-Q1.30 (OUT2M), TAC5212.22 (OUT2M)
OUT2M+: C123.2, D111.1 (K), R136.1, board_outline108.27 (OUT2M)
OUT2P: OUTP2.1, R131.2, R132.2, TAC108-Q1.29 (OUT2P), TAC5212.21 (OUT2P)
OUT2P+: C121.2, D110.1 (K), R133.1, board_outline108.25 (OUT2P)

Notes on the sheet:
TAC5212 AUDIO CODEC
POWER SUPPLY
MODULE IO
REPLACE WITH ANALOG BUFFER SUCH AS SN74LVC1G66 SO THERE IS NO CONTENTION BETWEEN THE SUB-MODULES!
DATA OUTPUT BUFFER
AUDIO FILTERS
T-DSP TAC5212 Pro Audio Module
POWER INDICATOR
# TAC5212 Audio Module - Input/Output Interface Documentation ## Document Control | Version | Date | Author | Changes | |---------|------|--------|---------| | 1.0 | [Date] | [Name] | Initial release | --- ## Module Overview The TAC5212 audio module provides flexible, high-quality audio input and o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
PANEL TABS

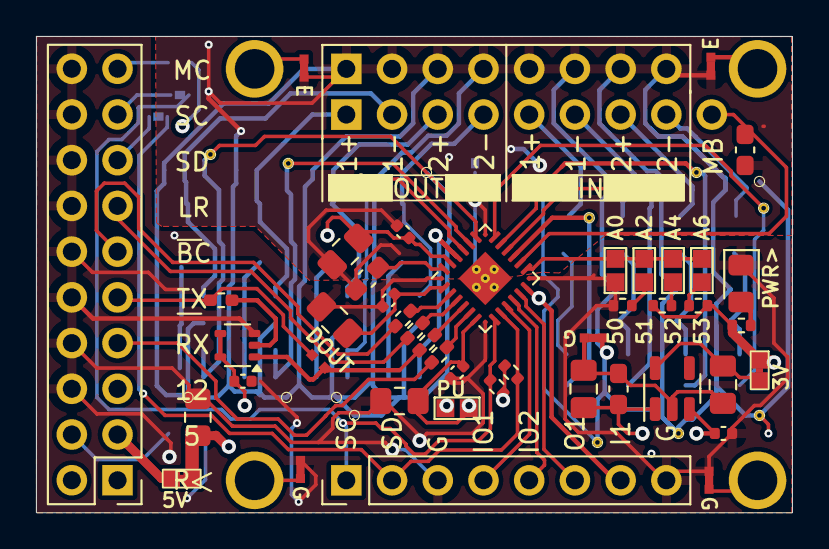
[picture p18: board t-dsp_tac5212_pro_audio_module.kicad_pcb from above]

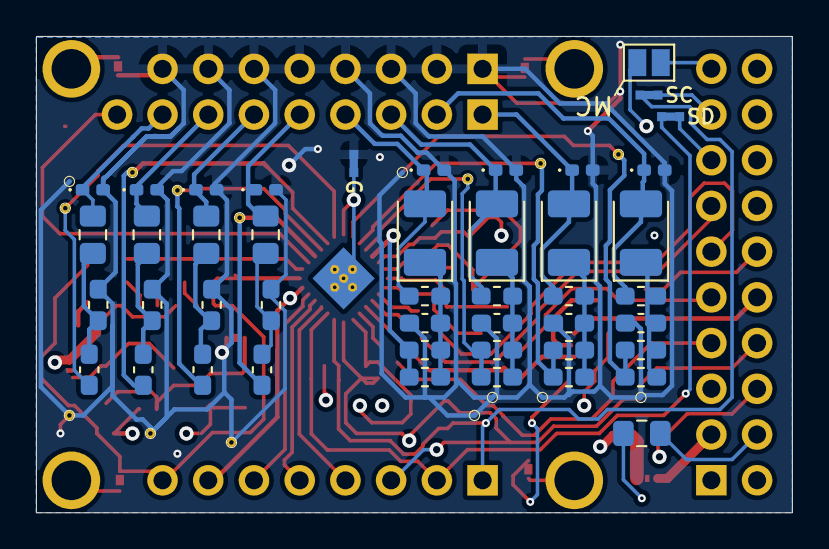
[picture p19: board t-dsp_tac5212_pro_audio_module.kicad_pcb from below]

Board: 4 copper layers, 42.0 x 26.5 mm, 110 parts (61 on the bottom side), 67 nets.

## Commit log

2024-08-25 added enable (held-high)
    [tac5212_audio_board_single_ended.kicad_pcb, tac5212_audio_board_single_ended.kicad_sch, tac5212_audio_board_single_ended.step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]
2025-01-06 update after a few builds.
    The 3.3v pin on the T-DSP connector is incorrect.
    [tac5212_audio_board_single_ended.kicad_sch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]
2025-01-07 update the module io for the 3v from digital audio board v1
    [tac5212_audio_board_single_ended.kicad_sch]
2025-04-21 adding documentation
    [EN11-HSM1AF15.STEP, LED_SK6812MINI-E.step, PEC12R-2220F-S0024.step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]
2026-02-07 Add Teensy and Teensy Audio Library references with links
2026-02-08 Fix README audio specs against TAC5212 datasheet
    Correct gain claim (12dB analog, not 60dB), input impedance
    (programmable 5k/10k/40k, not 100k), headphone power (62.5mW@16ohm,
    ~31mW@32ohm), output swing (2 VRMS differential), and label I/O as
    differential pairs.
2026-02-08 Correct README audio input specs
    Fix input voltage range to 2 VRMS differential, clarify instrument
    input requires external preamp/buffer, note preamp modules on roadmap.
2026-02-08 Add KiCanvas links for online schematic and PCB viewing
2026-02-08 Add interactive 3D model (STL) export of PCB
    Exported via kicad-cli. GitHub renders STL files interactively in the
    browser.
2026-02-09 fix all drc errors.
    [t-dsp_tac5212_pro_audio_module.kicad_pcb, t-dsp_tac5212_pro_audio_module.kicad_sch]
2026-02-09 Add KiBot CI/CD pipeline for JLCPCB manufacturing files
    - Add .kibot.yaml config for gerbers, drill, BOM, CPL, and ZIP output
    - Add GitHub Actions workflow triggered on push to main and manual dispatch
    - Add release job to attach JLCPCB ZIP to GitHub Releases on version tags
    - Fix malformed reference designators (5V108, 3V108) that blocked KiBot BOM/CPL
    - Add local build instructions to README
    [t-dsp_tac5212_pro_audio_module.kicad_pcb, t-dsp_tac5212_pro_audio_module.kicad_sch]
2026-02-09 Fix Package field conflicts and enable gerber job file
    - C128: Package C0603 → C0402 (matches footprint)
    - C124: Package C0805 → C0603 (matches footprint)
    - Enable gerber job file for automatic layer identification by fabs
    [t-dsp_tac5212_pro_audio_module.kicad_sch]
2026-02-09 Add schematic and PCB layout PDFs to manufacturing output
    [t-dsp_tac5212_pro_audio_module.kicad_sch]
2026-02-09 Add version, date, and license to manufacturing outputs
    - Add KiBot preflight to auto-populate REVISION (git tag) and DATE variables
    - Replace static "V0.91" silkscreen text with ${REVISION} variable
    - Add schematic title block with date, revision, copyright, and CC BY-NC-SA license
    - Remove reference designator printing from gerber silkscreen and PCB PDF
    - Hide footprint refs on F.Cu, F.SilkS, B.Cu, B.SilkS in PCB PDF output
    [t-dsp_tac5212_pro_audio_module.kicad_pcb, t-dsp_tac5212_pro_audio_module.kicad_sch]
2026-02-09 Add version to ZIP filename and PCB title block
    - Add PCB title_block with ${REVISION} so %r resolves in output filenames
    - ZIP now named t-dsp_tac5212_pro_audio_module-manufacturing_v0.98.zip etc.
    [t-dsp_tac5212_pro_audio_module.kicad_pcb]
2026-02-10 Add auto-generated PCB spec to manufacturing ZIP
    Adds a KiBot report output that generates board specifications
    (dimensions, layer stackup, materials, track/drill specs) from
    PCB metadata. Included in the manufacturing ZIP for manufacturer
    reference.
2026-02-10 Add 3D renders, hide ref designators, fix legacy 3D model paths
    - Add Blender 3D render output (8 views: top, bottom, 4 sides, 2 isometric)
    to KiBot config and manufacturing ZIP
    - Split CI workflow into 3 steps: manufacturing outputs, 3D renders
    (kicad9_auto_full), and ZIP packaging
    - Add PCB spec report to manufacturing outputs
    - Hide reference designators and component values from silkscreen
    - Replace legacy ${KISYS3DMOD} with ${KICAD9_3DMODEL_DIR} across all
    footprint libraries and PCB (47 files)
    - Add new 3D models (TPD1E10B06, VQFN-24) and footprints
    - Set net tie footprint type on jumper components
    [TPD1E10B06DPYR.STEP, VQFN-24-1EP_4x4mm_P0.5mm_EP2.45x2.45mm.step, t-dsp_tac5212_pro_audio_module.kicad_pcb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]

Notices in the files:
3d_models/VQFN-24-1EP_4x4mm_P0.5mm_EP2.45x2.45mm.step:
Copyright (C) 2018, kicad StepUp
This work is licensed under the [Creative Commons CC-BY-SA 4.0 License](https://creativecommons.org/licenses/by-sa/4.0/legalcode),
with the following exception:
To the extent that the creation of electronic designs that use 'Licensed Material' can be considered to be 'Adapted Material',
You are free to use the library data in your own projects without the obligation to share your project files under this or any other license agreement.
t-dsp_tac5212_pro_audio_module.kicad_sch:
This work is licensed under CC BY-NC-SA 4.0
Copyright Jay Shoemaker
